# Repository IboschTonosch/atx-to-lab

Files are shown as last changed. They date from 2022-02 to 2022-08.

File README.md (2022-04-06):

# atx-to-lab

You need the following tools to view or edit the files
* [KiCAD](https://kicad.org) - Edit PCB and Schematic files (.pro, .pcb, .sch).
* [FreeCAD](https://freecadweb.org) - Edit Assembly CAD Files.

Optional tools
* [Inkscape](https://inkscape.org) - Inkscape is a free and open-source vector graphics editor.

## Section Title
> What is this all about.

Complete design to turn an PC atx power supply into a constant current lab power supply

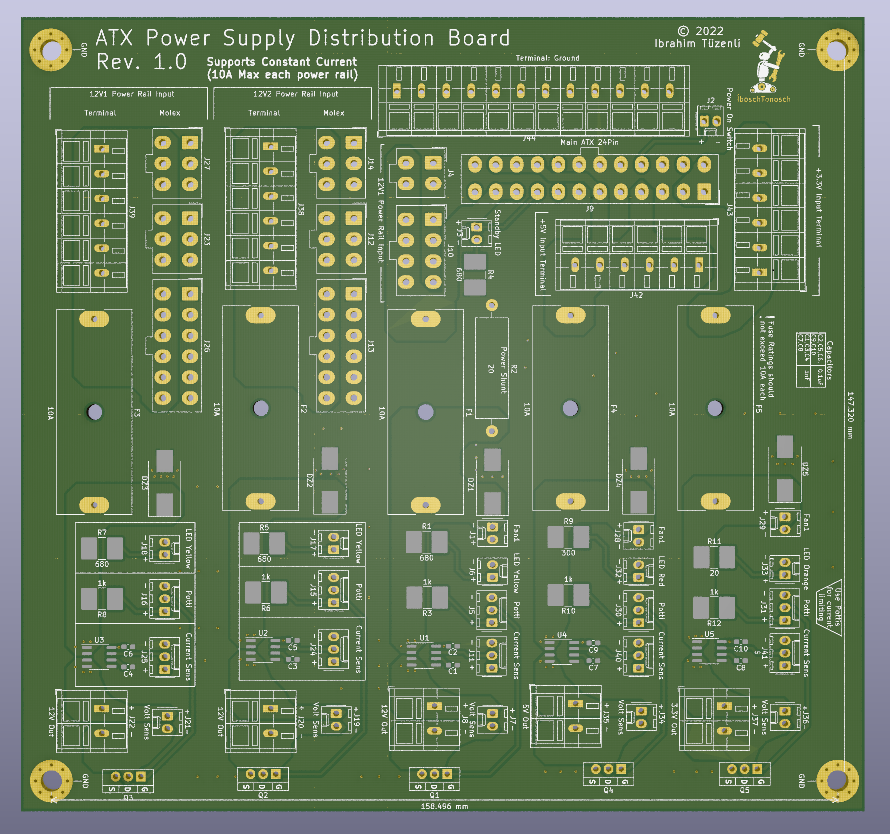
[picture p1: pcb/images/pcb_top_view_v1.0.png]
PCB_TOP_VIEW


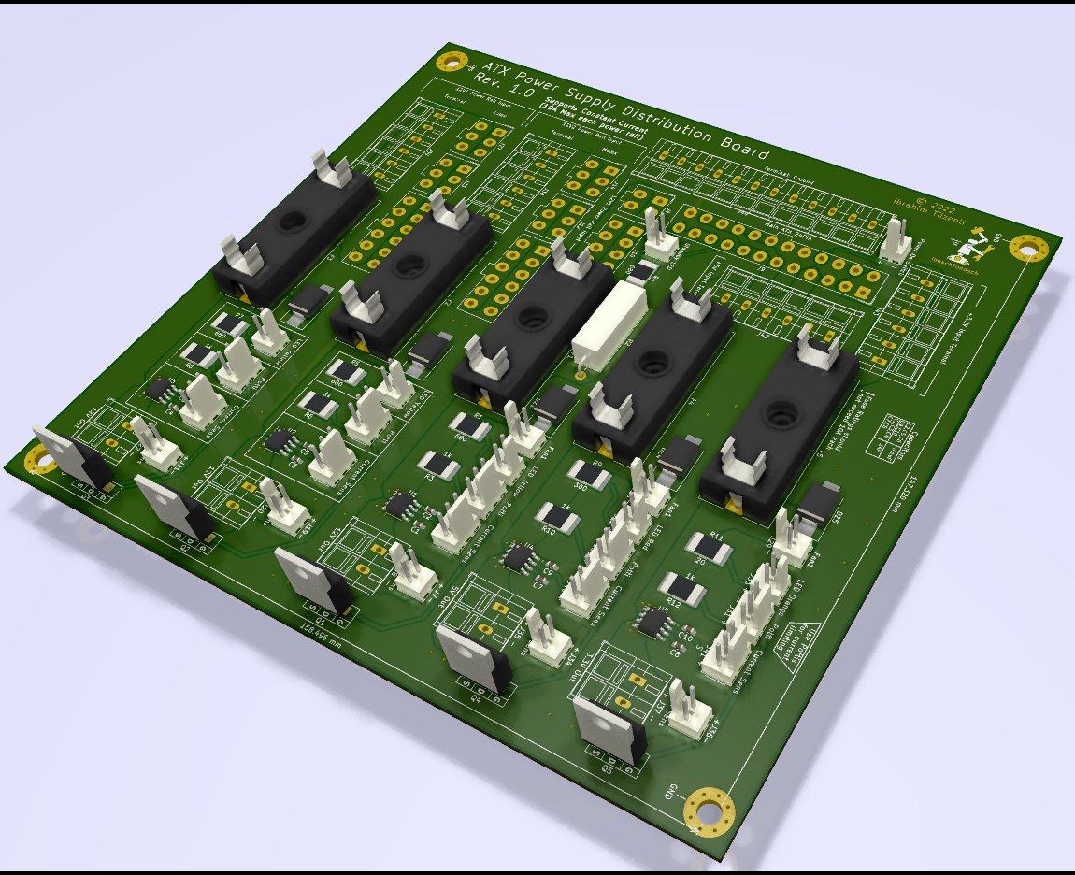
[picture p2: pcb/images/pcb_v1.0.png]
PCB_SIDE_VIEW


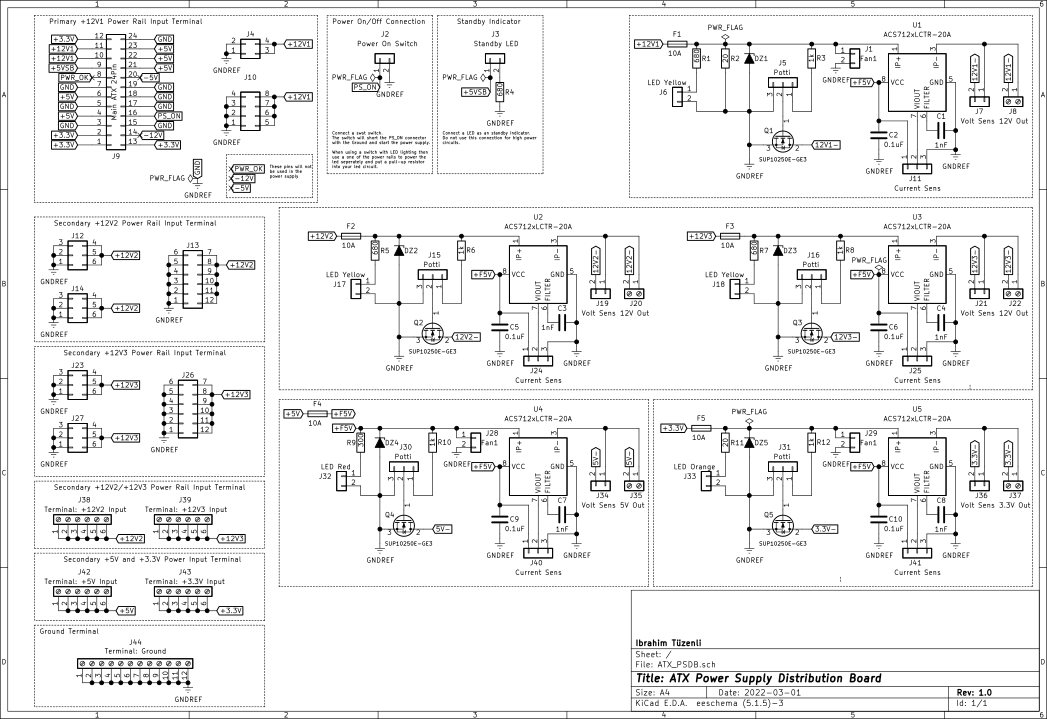
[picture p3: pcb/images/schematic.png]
Schematic


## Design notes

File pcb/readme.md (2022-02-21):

Selection of the Mosfets

V_DDS			: >30V
R_DS(on)(Max)	: < 20mOhm
I_D				: >40A
P_D 			: ?

Termal Resistance, junction - ambient = 62.5 °c/W

Temperature on Load with (10A and 20mOhm):
Pd = I^2 * Rds = 10A^2 * 20^(-3)Ohm = 2W
dT = 2W * 62.5°C / W = 125°C
Room Temp = 25°C
Junction Temp = 25°C + 125°C = 150°C

Result:
150°C is too high and would probably damage the mosfet.
also can it produce stronger signal noises

If this is unavoidable then a heat sink is recommended to keep the junction temperature low

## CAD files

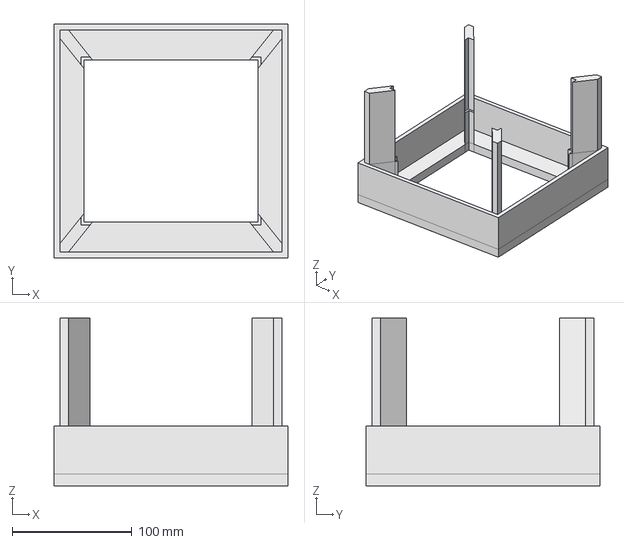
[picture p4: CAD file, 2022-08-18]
housing/frame.FCStd
195.0 x 195.0 x 140.0 mm

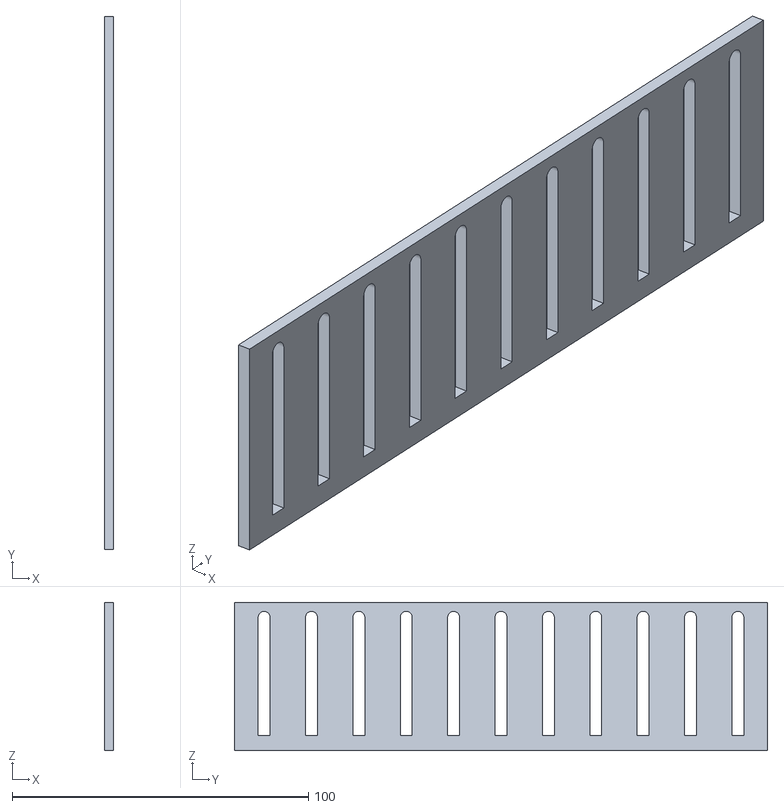
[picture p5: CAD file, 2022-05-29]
housing/stl/frame-sidePanel.stl
3.00 x 180.0 x 50.0

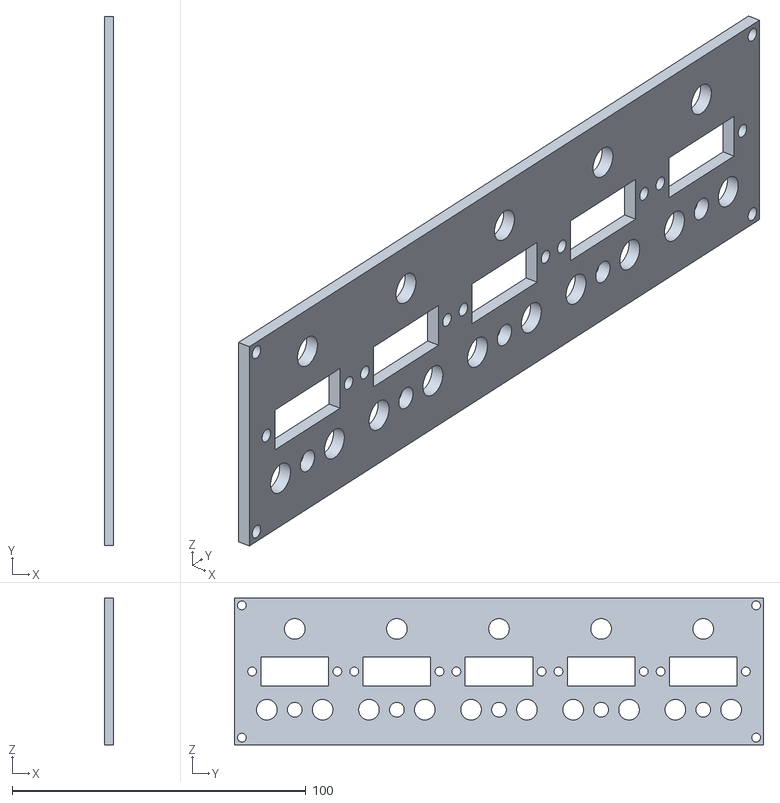
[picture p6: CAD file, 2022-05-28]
housing/stl/frame-FrontPanel.stl
3.00 x 180.0 x 50.0

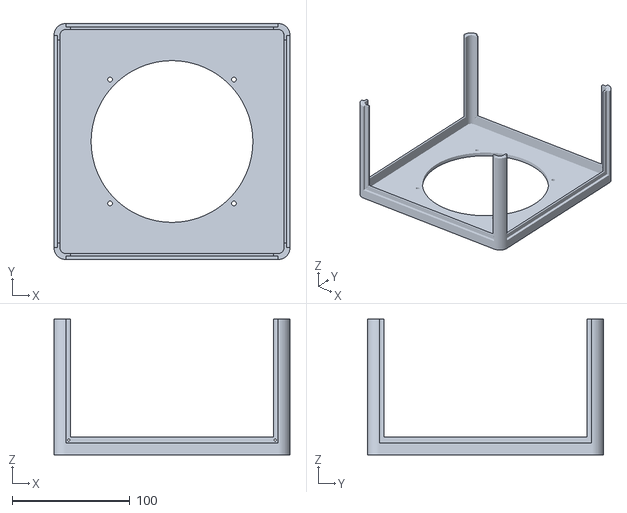
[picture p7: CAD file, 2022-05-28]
housing/stl/frame_top_fan.stl
200.0 x 200.0 x 115.0

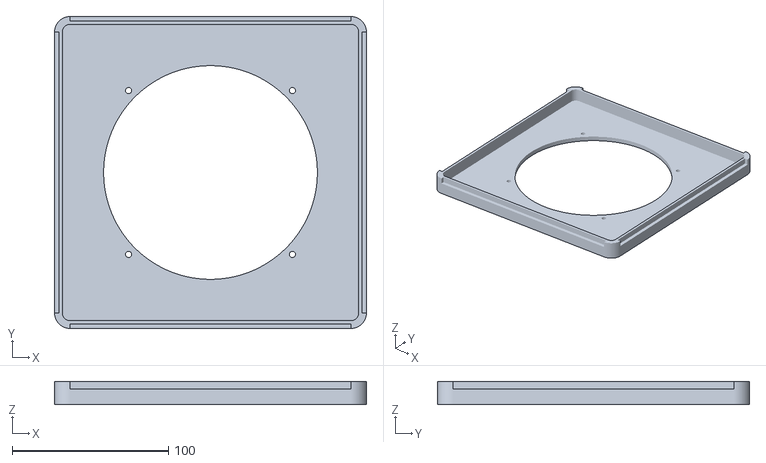
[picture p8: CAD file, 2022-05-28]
housing/stl/frame_top_fan_bare.stl
200.0 x 200.0 x 15.0

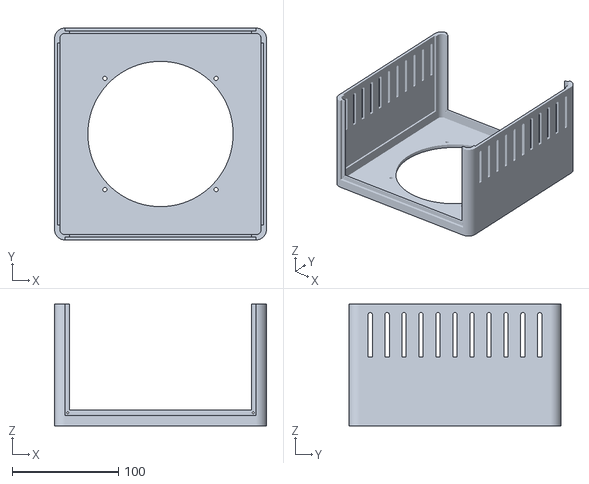
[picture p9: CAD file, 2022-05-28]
housing/stl/frame_top_fan_with_side_plates.stl
200.0 x 200.0 x 115.0

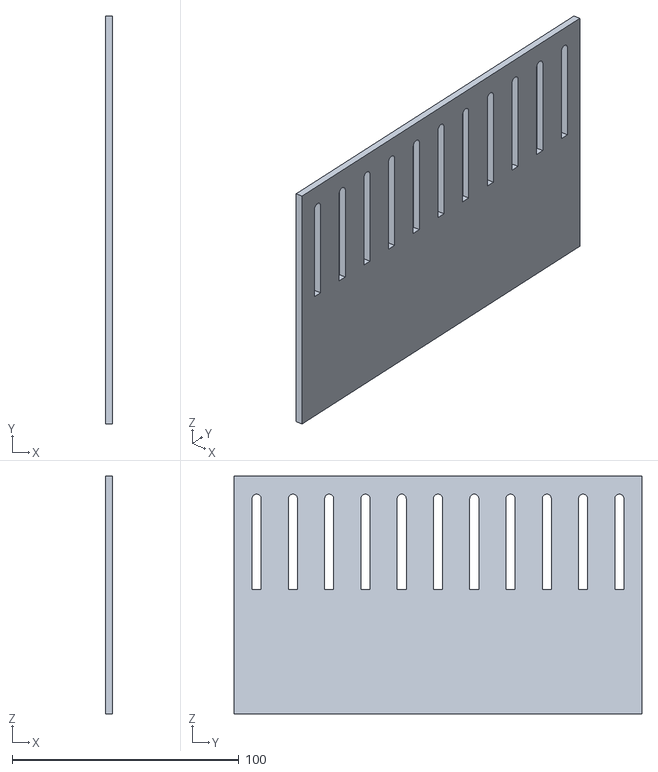
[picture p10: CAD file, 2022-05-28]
housing/stl/frame_side_plate.stl
3.00 x 180.0 x 105.0

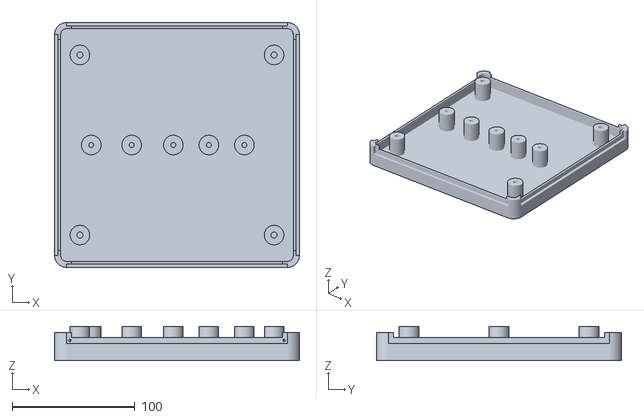
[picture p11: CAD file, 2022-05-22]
housing/stl/frame_bottom.stl
200.0 x 200.0 x 28.0

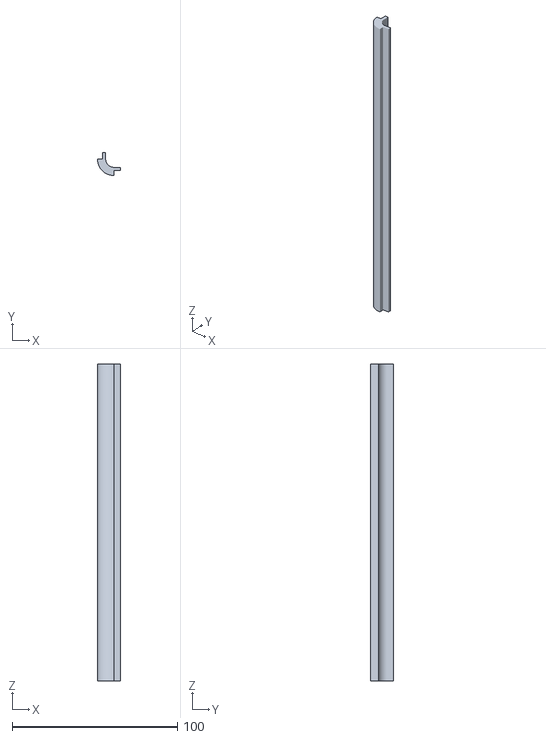
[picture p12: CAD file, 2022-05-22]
housing/stl/frame_support_single.stl
14.0 x 14.0 x 192.0

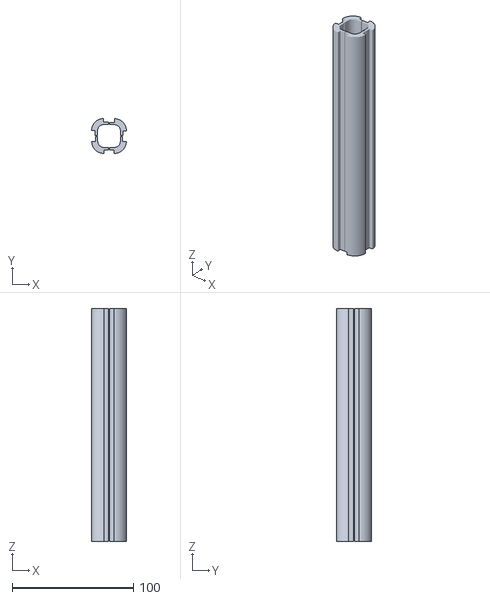
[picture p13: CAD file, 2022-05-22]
housing/stl/frame_support.stl
28.8 x 28.8 x 192.0

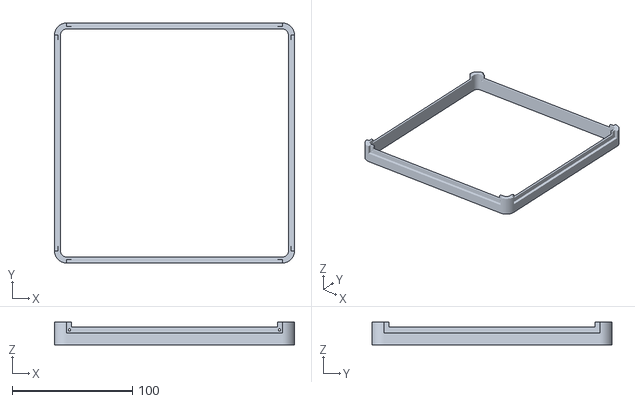
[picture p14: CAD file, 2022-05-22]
housing/stl/frame_top.stl
200.0 x 200.0 x 19.0

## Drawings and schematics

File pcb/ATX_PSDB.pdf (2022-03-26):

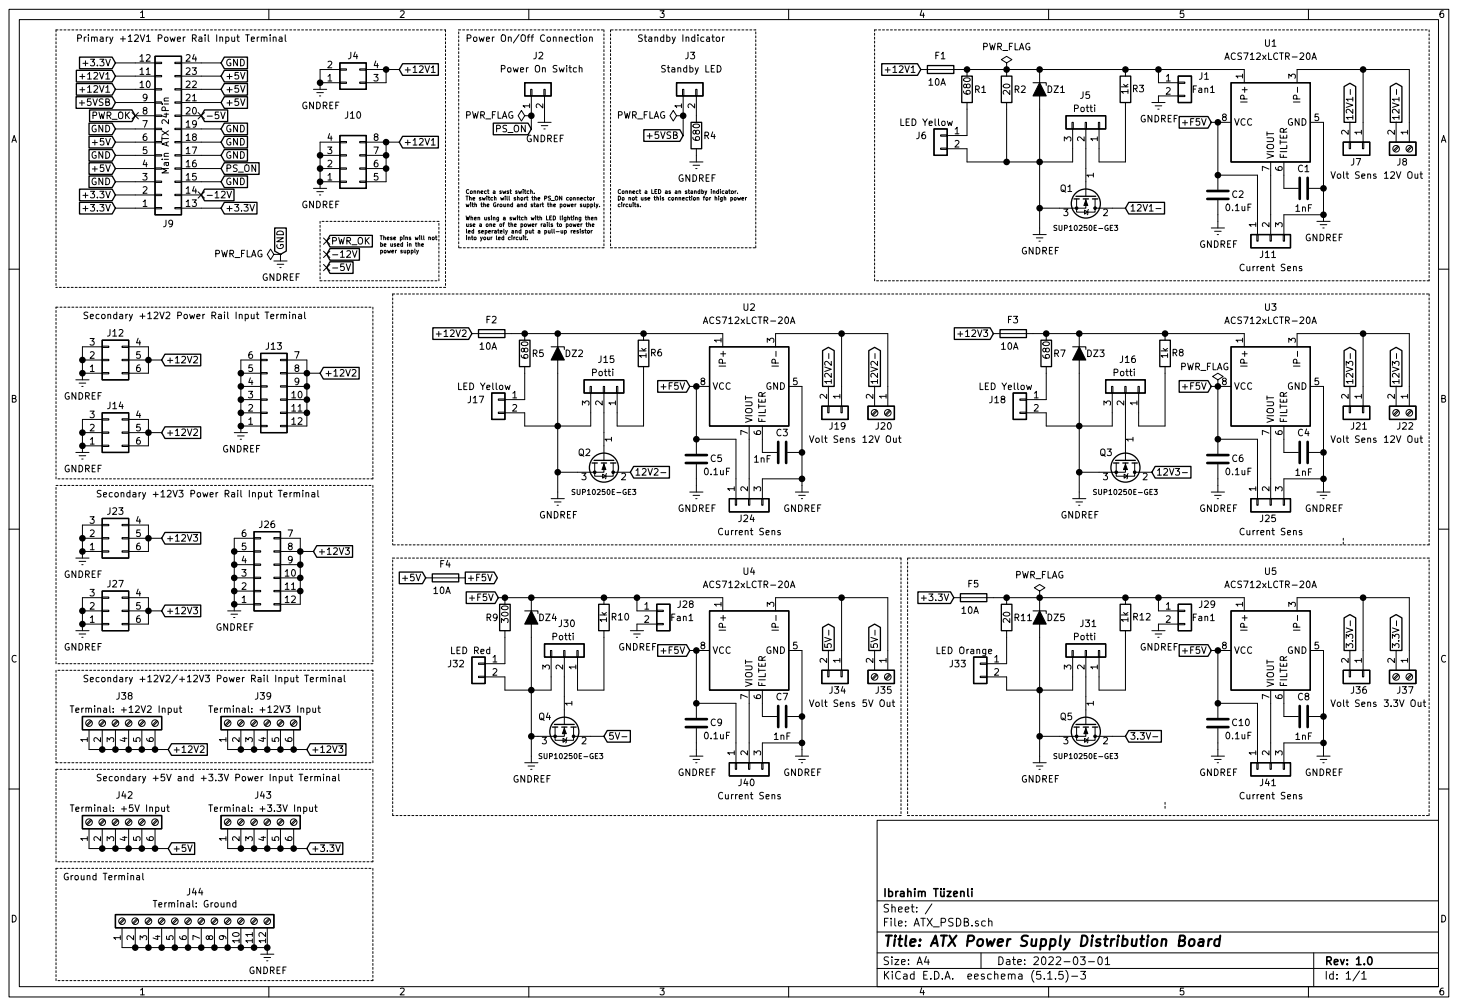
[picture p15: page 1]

Primary +12V1 Power Rail Input Terminal

use a one of the power rails to power the
led seperately and put a pull-up resistor

into your led circuit. Secondary +12V2 Power Rail Input Terminal

3 | 10

SUP10250E-GE3 1
Secondary +12V3 Power Rail Input Terminal Ground Terminal Secondary +5V and +3.3V Power Input Terminal

2 | 11
1 | 12

Secondary +12V2/+12V3 Power Rail Input Terminal
J38 Terminal: +12V2 Input

File: ATX_PSDB.sch Sheet: /
Id: 1/1 Title: ATX Power Supply Distribution Board

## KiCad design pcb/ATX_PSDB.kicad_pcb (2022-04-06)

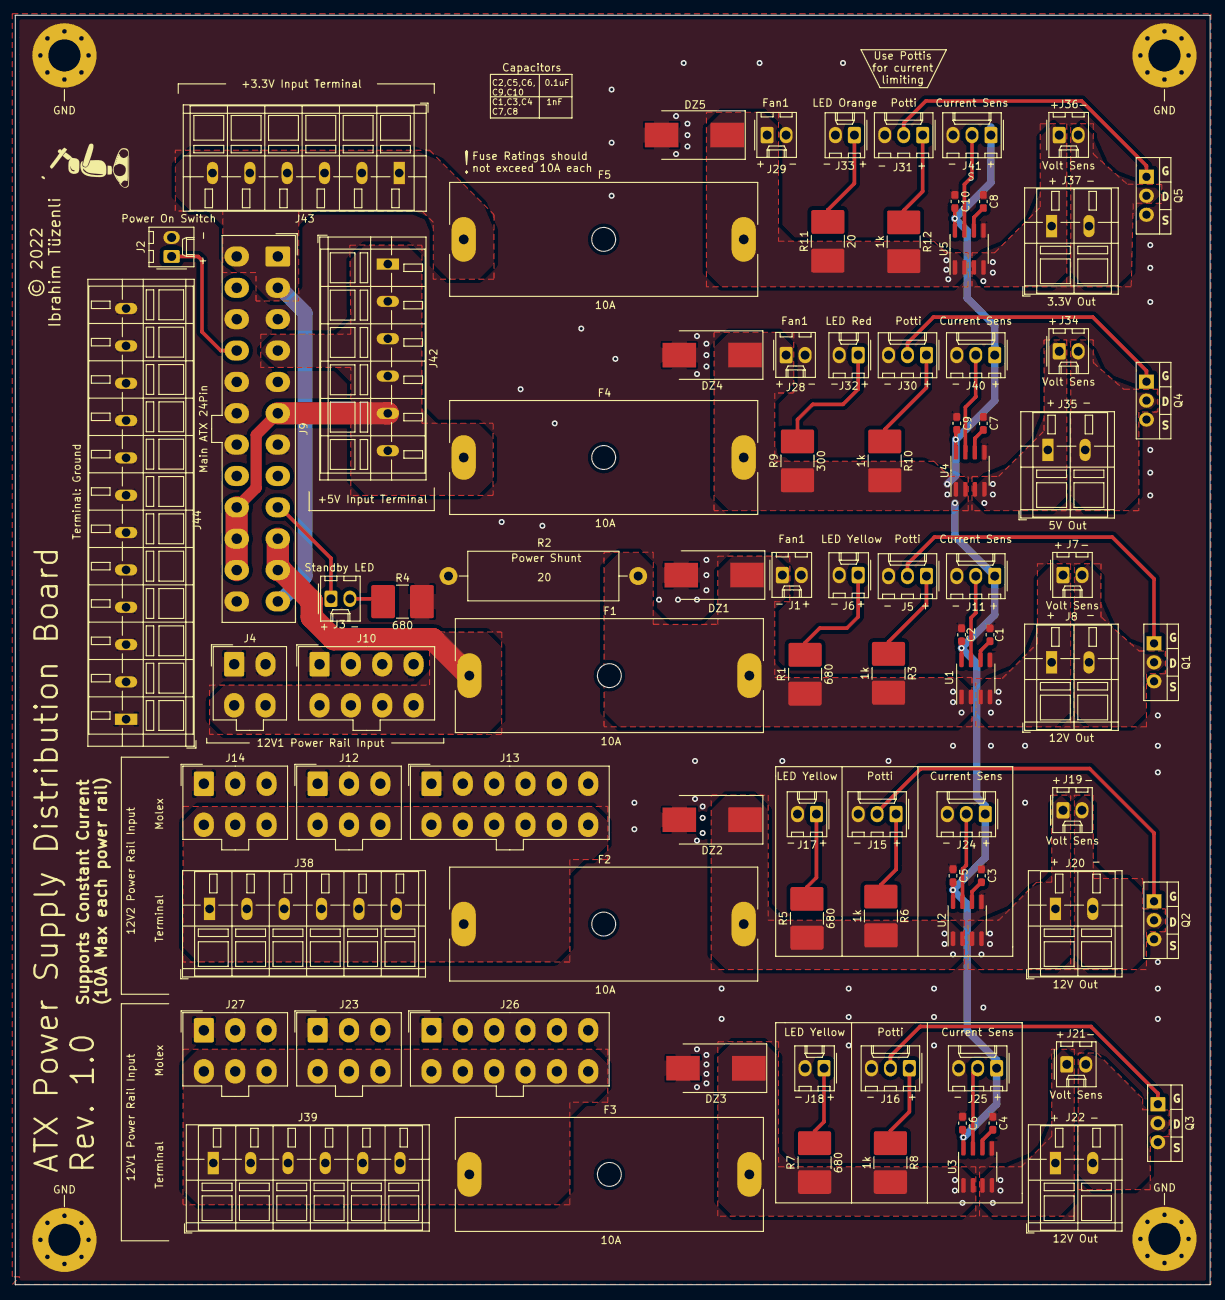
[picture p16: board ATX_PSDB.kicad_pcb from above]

Board: 2 copper layers, 160.0 x 170.0 mm, 86 parts (0 on the bottom side), 49 nets.

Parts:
C1, C3, C4, C7, C8: 1nF; C_0603_1608Metric_Pad1.05x0.95mm_HandSolder
C2, C5, C6, C9, C10: 0.1uF; C_0603_1608Metric_Pad1.05x0.95mm_HandSolder
DZ1, DZ2, DZ3, DZ4, DZ5: D_Zener_ALT; D_SMC_Handsoldering
F1, F2, F3, F4, F5: 10A; Fuseholder_Cylinder-6.3x32mm_Schurter_0031-8002_Horizontal_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
J1, J28, J29: Fan1; Molex_KK-254_AE-6410-02A_1x02_P2.54mm_Vertical
J2: Power On Switch; Molex_KK-254_AE-6410-02A_1x02_P2.54mm_Vertical
J3: Standby LED; Molex_KK-254_AE-6410-02A_1x02_P2.54mm_Vertical
J4: ATX 12V1 Input; Molex_Mini-Fit_Jr_5566-04A_2x02_P4.20mm_Vertical
J5, J15, J16, J30, J31: Potti; Molex_KK-254_AE-6410-03A_1x03_P2.54mm_Vertical
J6, J17, J18: LED Yellow; Molex_KK-254_AE-6410-02A_1x02_P2.54mm_Vertical
J7, J19, J21, J34, J36: Volt Sens; Molex_KK-254_AE-6410-02A_1x02_P2.54mm_Vertical
J8, J20, J22: 12V Out; TerminalBlock_WAGO_236-102_1x02_P5.00mm_45Degree
J9: Main ATX 24Pin; Molex_Mini-Fit_Jr_5566-24A_2x12_P4.20mm_Vertical
J10: ATX 12V1 Input; Molex_Mini-Fit_Jr_5566-08A_2x04_P4.20mm_Vertical
J11, J24, J25, J40, J41: Current Sens; Molex_KK-254_AE-6410-03A_1x03_P2.54mm_Vertical
J12, J14: Molex: ATX 12V2 Input; Molex_Mini-Fit_Jr_5566-06A_2x03_P4.20mm_Vertical
J13: Molex: ATX 12V2 Input; Molex_Mini-Fit_Jr_5566-12A_2x06_P4.20mm_Vertical
J23, J27: Molex: ATX 12V3 Input; Molex_Mini-Fit_Jr_5566-06A_2x03_P4.20mm_Vertical
J26: Molex: ATX 12V3 Input; Molex_Mini-Fit_Jr_5566-12A_2x06_P4.20mm_Vertical
J32: LED Red; Molex_KK-254_AE-6410-02A_1x02_P2.54mm_Vertical
J33: LED Orange; Molex_KK-254_AE-6410-02A_1x02_P2.54mm_Vertical
J35: 5V Out; TerminalBlock_WAGO_236-102_1x02_P5.00mm_45Degree
J37: 3.3V Out; TerminalBlock_WAGO_236-102_1x02_P5.00mm_45Degree
J38: Terminal: +12V2 Input; TerminalBlock_WAGO_236-106_1x06_P5.00mm_45Degree
J39: Terminal: +12V3 Input; TerminalBlock_WAGO_236-106_1x06_P5.00mm_45Degree
J42: Terminal: +5V Input; TerminalBlock_WAGO_236-106_1x06_P5.00mm_45Degree
J43: Terminal: +3.3V Input; TerminalBlock_WAGO_236-106_1x06_P5.00mm_45Degree
J44: Terminal: Ground; TerminalBlock_WAGO_236-112_1x12_P5.00mm_45Degree
Q1, Q2, Q3, Q4, Q5: Q_NMOS_DGS; TO-220-3_Vertical
R1, R4, R5, R7: 680; R_2816_7142Metric_Pad3.20x4.45mm_HandSolder
R2: 20; R_Axial_Power_L20.0mm_W6.4mm_P25.40mm
R3, R6, R8, R10, R12: 1k; R_2816_7142Metric_Pad3.20x4.45mm_HandSolder
R9: 300; R_2816_7142Metric_Pad3.20x4.45mm_HandSolder
R11: 20; R_2816_7142Metric_Pad3.20x4.45mm_HandSolder
U1, U2, U3, U4, U5: ACS712xLCTR-20A; SOIC-8_3.9x4.9mm_P1.27mm

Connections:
3.3V-: J36.2, J37.2, Q5.2
5V-: J34.2, J35.2, Q4.2
12V1-: J7.2, J8.2, Q1.2
12V2-: J19.2, J20.2, Q2.2
12V3-: J21.2, J22.2, Q3.2
+3.3V: F5.1, J9.1, J9.2, J9.12, J9.13, J43.1, J43.2, J43.3, J43.4, J43.5, J43.6
+5V: F4.1, J9.4, J9.6, J9.21, J9.22, J9.23, J42.1, J42.2, J42.3, J42.4, J42.5, J42.6
+5VSB: J3.1, J9.9
+12V1: F1.1, J4.3, J4.4, J9.10, J9.11, J10.5, J10.6, J10.7, J10.8
+12V2: F2.1, J12.4, J12.5, J12.6, J13.7, J13.8, J13.9, J13.10, J13.11, J13.12, J14.4, J14.5, J14.6, J38.1, J38.2, J38.3, J38.4, J38.5, J38.6
+12V3: F3.1, J23.4, J23.5, J23.6, J26.7, J26.8, J26.9, J26.10, J26.11, J26.12, J27.4, J27.5, J27.6, J39.1, J39.2, J39.3, J39.4, J39.5, J39.6
+F5V: C2.2, C5.2, C6.2, C9.2, C10.2, DZ4.1, F4.2, J11.1, J24.1, J25.1, J28.1, J40.1, J41.1, R9.1, R10.2, U1.8, U2.8, U3.8, U4.1, U4.2, U4.8, U5.8
GND: C1.1, C2.1, C3.1, C4.1, C5.1, C6.1, C7.1, C8.1, C9.1, C10.1, DZ1.2, DZ2.2, DZ3.2, DZ4.2, DZ5.2, J1.2, J2.2, J4.1, J4.2, J5.3, J6.2, J9.3, J9.5, J9.7, J9.15, J9.17, J9.18, J9.19, J9.24, J10.1, J10.2, J10.3, J10.4, J11.3, J12.1, J12.2, J12.3, J13.1, J13.2, J13.3, J13.4, J13.5, J13.6, J14.1, J14.2, J14.3, J15.3, J16.3, J17.2, J18.2, J23.1, J23.2, J23.3, J24.3, J25.3, J26.1, J26.2, J26.3, J26.4, J26.5, J26.6, J27.1, J27.2, J27.3, J28.2, J29.2, J30.3, J31.3, J32.2, J33.2, J40.3, J41.3, J44.1, J44.2, J44.3, J44.4, J44.5, J44.6, J44.7, J44.8, J44.9, J44.10, J44.11, J44.12, Q1.3, Q2.3, Q3.3, Q4.3, Q5.3, R2.2, R4.2, U1.5, U2.5, U3.5, U4.5, U5.5
unnamed: C1.2, U1.6
unnamed: C3.2, U2.6
unnamed: C4.2, U3.6
unnamed: C7.2, U4.6
unnamed: C8.2, U5.6
unnamed: DZ1.1, F1.2, J1.1, R1.1, R2.1, R3.2, U1.1, U1.2
unnamed: DZ2.1, F2.2, R5.1, R6.2, U2.1, U2.2
unnamed: DZ3.1, F3.2, R7.1, R8.2, U3.1, U3.2
unnamed: DZ5.1, F5.2, J29.1, R11.1, R12.2, U5.1, U5.2
unnamed: J3.2, R4.1
unnamed: J5.1, R3.1
unnamed: J5.2, Q1.1
unnamed: J6.1, R1.2
unnamed: J7.1, J8.1, U1.3, U1.4
unnamed: J11.2, U1.7
unnamed: J15.1, R6.1
unnamed: J15.2, Q2.1
unnamed: J16.1, R8.1
unnamed: J16.2, Q3.1
unnamed: J17.1, R5.2
unnamed: J18.1, R7.2
unnamed: J19.1, J20.1, U2.3, U2.4
unnamed: J21.1, J22.1, U3.3, U3.4
unnamed: J24.2, U2.7
unnamed: J25.2, U3.7
unnamed: J30.1, R10.1
unnamed: J30.2, Q4.1
unnamed: J31.1, R12.1
unnamed: J31.2, Q5.1
unnamed: J32.1, R9.2
unnamed: J33.1, R11.2
unnamed: J34.1, J35.1, U4.3, U4.4
unnamed: J36.1, J37.1, U5.3, U5.4
unnamed: J40.2, U4.7
unnamed: J41.2, U5.7
PS_ON: J2.1, J9.16

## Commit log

2020-06-20 Adding gitignore for kicad project
2020-06-20 Adding KiCad project
    [ATX_PSU_525W_ENERMAX.kicad_pcb, ATX_PSU_525W_ENERMAX.sch, MainPowerInput.sch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]
2021-10-07 protection changes
    [SecondaryPowerInput.sch]
2022-01-15 moved all sub schematics to base schematic sheet due to minor complexity
    [ATX_PSU_525W_ENERMAX.sch, MainsOVPOVPsch.sch, SecondaryPowerInput.sch]
2022-02-27 Finalizing and labeling schematics
2022-02-28 Annotated schematic symbols
    [ATX_PSU_525W_ENERMAX.sch]
2022-02-28 performed rule check
    [ATX_PSU_525W_ENERMAX.sch]
2022-02-28 Assigned pcb footprints
    [ATX_PSU_525W_ENERMAX.sch]
2022-03-09 some cleanup
    [ATX_PSDB.kicad_pcb, ATX_PSDB.sch, MainPowerInput.sch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]
2022-03-12 changed terminal blocks to wago footprints
    [ATX_PSDB.kicad_pcb, ATX_PSDB.sch]
2022-03-13 More pcb layout
    [ATX_PSDB.kicad_pcb, ATX_PSDB.sch]
2022-03-17 densified circuit, defined edge cut, added mounting holes
    [ATX_PSDB.kicad_pcb, ATX_PSDB.sch]
2022-03-18 Adding Traces
    [ATX_PSDB.kicad_pcb]
2022-03-18 More traces
    [ATX_PSDB.kicad_pcb]
2022-03-19 refit traces, added global label added text
    [ATX_PSDB.kicad_pcb, ATX_PSDB.sch]
2022-03-19 Corrections and so on
    [ATX_PSDB.kicad_pcb, ATX_PSDB.sch]
2022-03-20 finalization Rev. 1.0
    [ATX_PSDB.kicad_pcb]
2022-03-21 Added Trademark, cleanup and so on
    [ATX_PSDB.kicad_pcb]
2022-03-21 Schematic corrections and new netlist generated
    [ATX_PSDB.sch]
2022-03-23 redesigned logo
    [ATX_PSDB.kicad_pcb]
2022-03-26 Changed File Structure
    [ATX_PSDB.kicad_pcb, ATX_PSDB.sch]
2022-03-26 renaming files, editing readme
    [ATX_PSDB.kicad_pcb, ATX_PSDB.sch]
2022-04-06 Migrate to KiCad 6.0
    [ATX_PSDB.kicad_pcb, ATX_PSDB.kicad_sch, ATX_PSDB.sch]
2022-05-09 Starting Frame Design
    [frame.FCStd]
2022-05-14 baseplate sketch
    [frame.FCStd]
2022-05-22 housing base fillets
    [frame.FCStd]
2022-05-22 added inner increasing of the base plane
    [frame.FCStd]
2022-05-22 created final base pad
    [frame.FCStd]
2022-05-22 startet housing
    [frame.FCStd]
2022-05-22 giving more structure
    [frame.FCStd]
2022-05-22 finished frame and provided stl files
    [frame.FCStd, frame_bottom.stl, frame_support.stl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]
2022-05-28 changed frame style slightly
    [frame.FCStd]
2022-05-28 designed top frame
    [frame.FCStd]
2022-05-28 frame top done
    [frame.FCStd]
2022-05-28 sketching front panel
    [frame.FCStd, frame_side_plate.stl, frame_top_fan.stl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]
2022-05-28 Front Panel finished
    [frame-FrontPanel.stl, frame.FCStd]
2022-05-28 added screw holes
    [frame.FCStd]
2022-05-29 resized side panel
    [frame-sidePanel.stl, frame.FCStd]
2022-08-18 added atx base stand
    [frame.FCStd]
2022-08-18 base atx stand
    [frame.FCStd]

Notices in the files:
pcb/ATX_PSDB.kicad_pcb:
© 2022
